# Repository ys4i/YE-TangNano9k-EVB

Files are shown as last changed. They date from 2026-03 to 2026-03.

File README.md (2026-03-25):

# YE-TangNano9k-EValuationBoard

コミックマーケット(C106)同人誌用TangNano9kの開発ボードです  
某月電子通商 Bタイプ基板(95×72mm)と寸法に互換性があります  
`販売コード[110243] B基板用アクリルパネル(アクリル板) 2mm厚(透明)`  
などでパネルを作れます

Tang Nano 9Kを用いた評価用ボードです。KiCad 9.0.3で設計されており、コミックマーケット(C106)頒布向けに作成されました。

## 特長
- 基板サイズ: 95 mm × 72 mm。某月電子通商 Bタイプ基板と同寸で、市販のB基板用アクリルパネルが使用可能。
- Seeed Studio製Tang Nano 9Kモジュールを搭載 (U1)。
- 24ピン×2列の拡張用ソケットコネクタを左右に配置 (J1, J2)。
- 4桁7セグメントLED表示器 OSL40391-IRA を搭載し、簡単な数値表示が可能。
- ブザー UGCM1205XP と、駆動用NPNトランジスタ 2SC1815 (Q1) を装備。
- 入力インターフェースとして SPDTスイッチ (SW1) とタクトスイッチ2個 (SW2, SW3) を搭載。

## プロジェクト構成
- `YE-tangnano9k-EVB.kicad_pro` : プロジェクト設定ファイル
- `YE-tangnano9k-EVB.kicad_sch` : 回路図
- `YE-tangnano9k-EVB.kicad_pcb` : 基板レイアウト
- `docs/YE-tangnano9k-EVB.pdf` : 回路図・基板図の閲覧用PDF
- `sym-lib-table` : シンボルライブラリ設定

## 使い方
KiCad 9.0以降で `.kicad_pro` ファイルを開き、回路図や基板データを編集してください。ファイル形式の詳細は [KiCad File Formats Documentation](https://dev-docs.kicad.org/en/file-formats/index.html) を参照してください。

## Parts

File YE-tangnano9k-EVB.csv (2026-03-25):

Reference | Qty | Value | Footprint | Datasheet
U2 | 1 | OSL40391-IRA | yasushi:OSL40391-Ixx | https://akizukidenshi.com/catalog/g/g109970/
U1 | 1 | Tang Nano 9K | yasushi:tangnano9k
SW2,SW3 | 2 | SW_Push | Button_Switch_THT:SW_PUSH_6mm_H7.3mm
SW1 | 1 | SW_SPDT | yasushi:2MS1-T1-B4-VS2-Q-E-S
R9,R11 | 2 | 10k | Resistor_THT:R_Axial_DIN0207_L6.3mm_D2.5mm_P10.16mm_Horizontal
R1,R2,R3,R4,R5,R6,R7,R8,R10 | 9 | 680 | Resistor_THT:R_Axial_DIN0207_L6.3mm_D2.5mm_P10.16mm_Horizontal
Q1 | 1 | 2SC1815 | Package_TO_SOT_THT:TO-92_Inline_Wide | https://media.digikey.com/pdf/Data%20Sheets/Toshiba%20PDFs/2SC1815.pdf
J1,J2 | 2 | Conn_01x24_Socket | Connector_PinSocket_2.54mm:PinSocket_1x24_P2.54mm_Vertical
BZ1 | 1 | UGCM1205XP | Buzzer_Beeper:Buzzer_12x9.5RM7.6

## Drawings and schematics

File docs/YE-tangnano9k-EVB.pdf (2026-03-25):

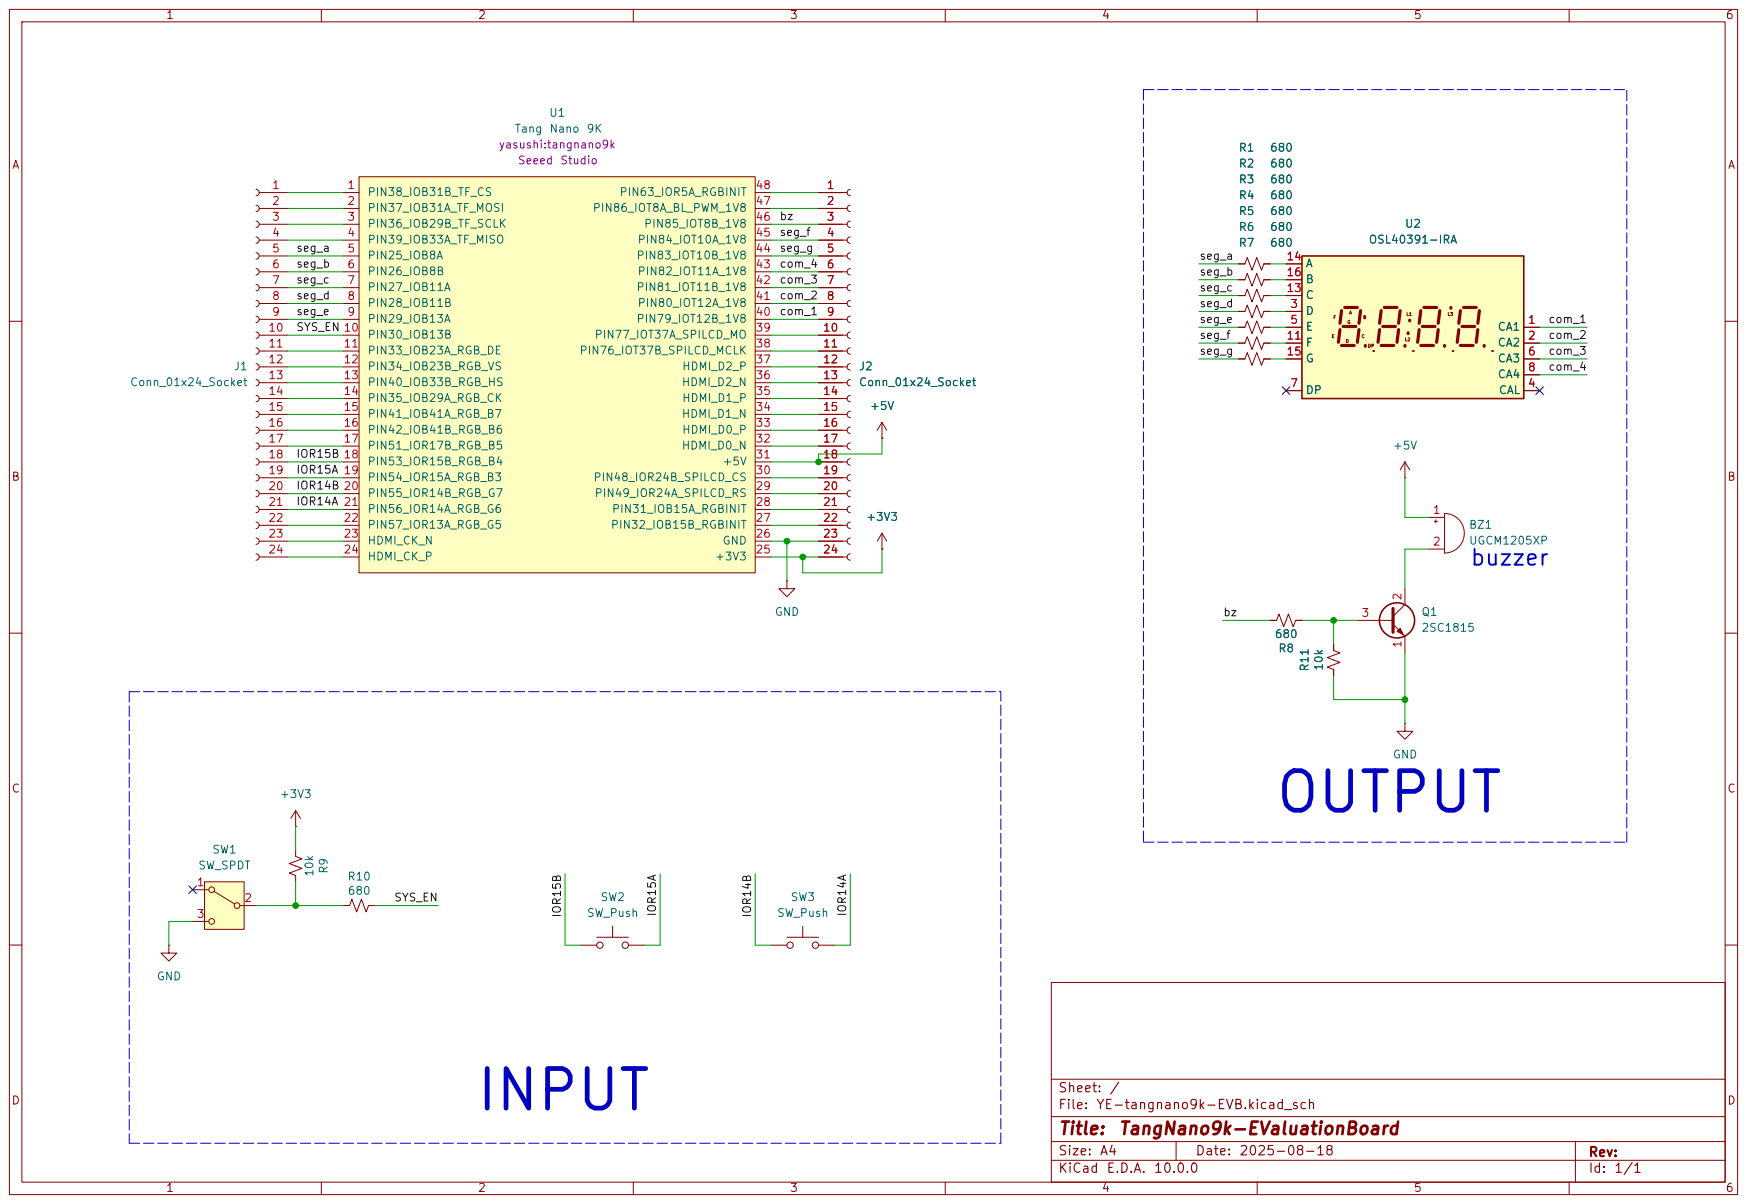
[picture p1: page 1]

Size: A4 | Rev:

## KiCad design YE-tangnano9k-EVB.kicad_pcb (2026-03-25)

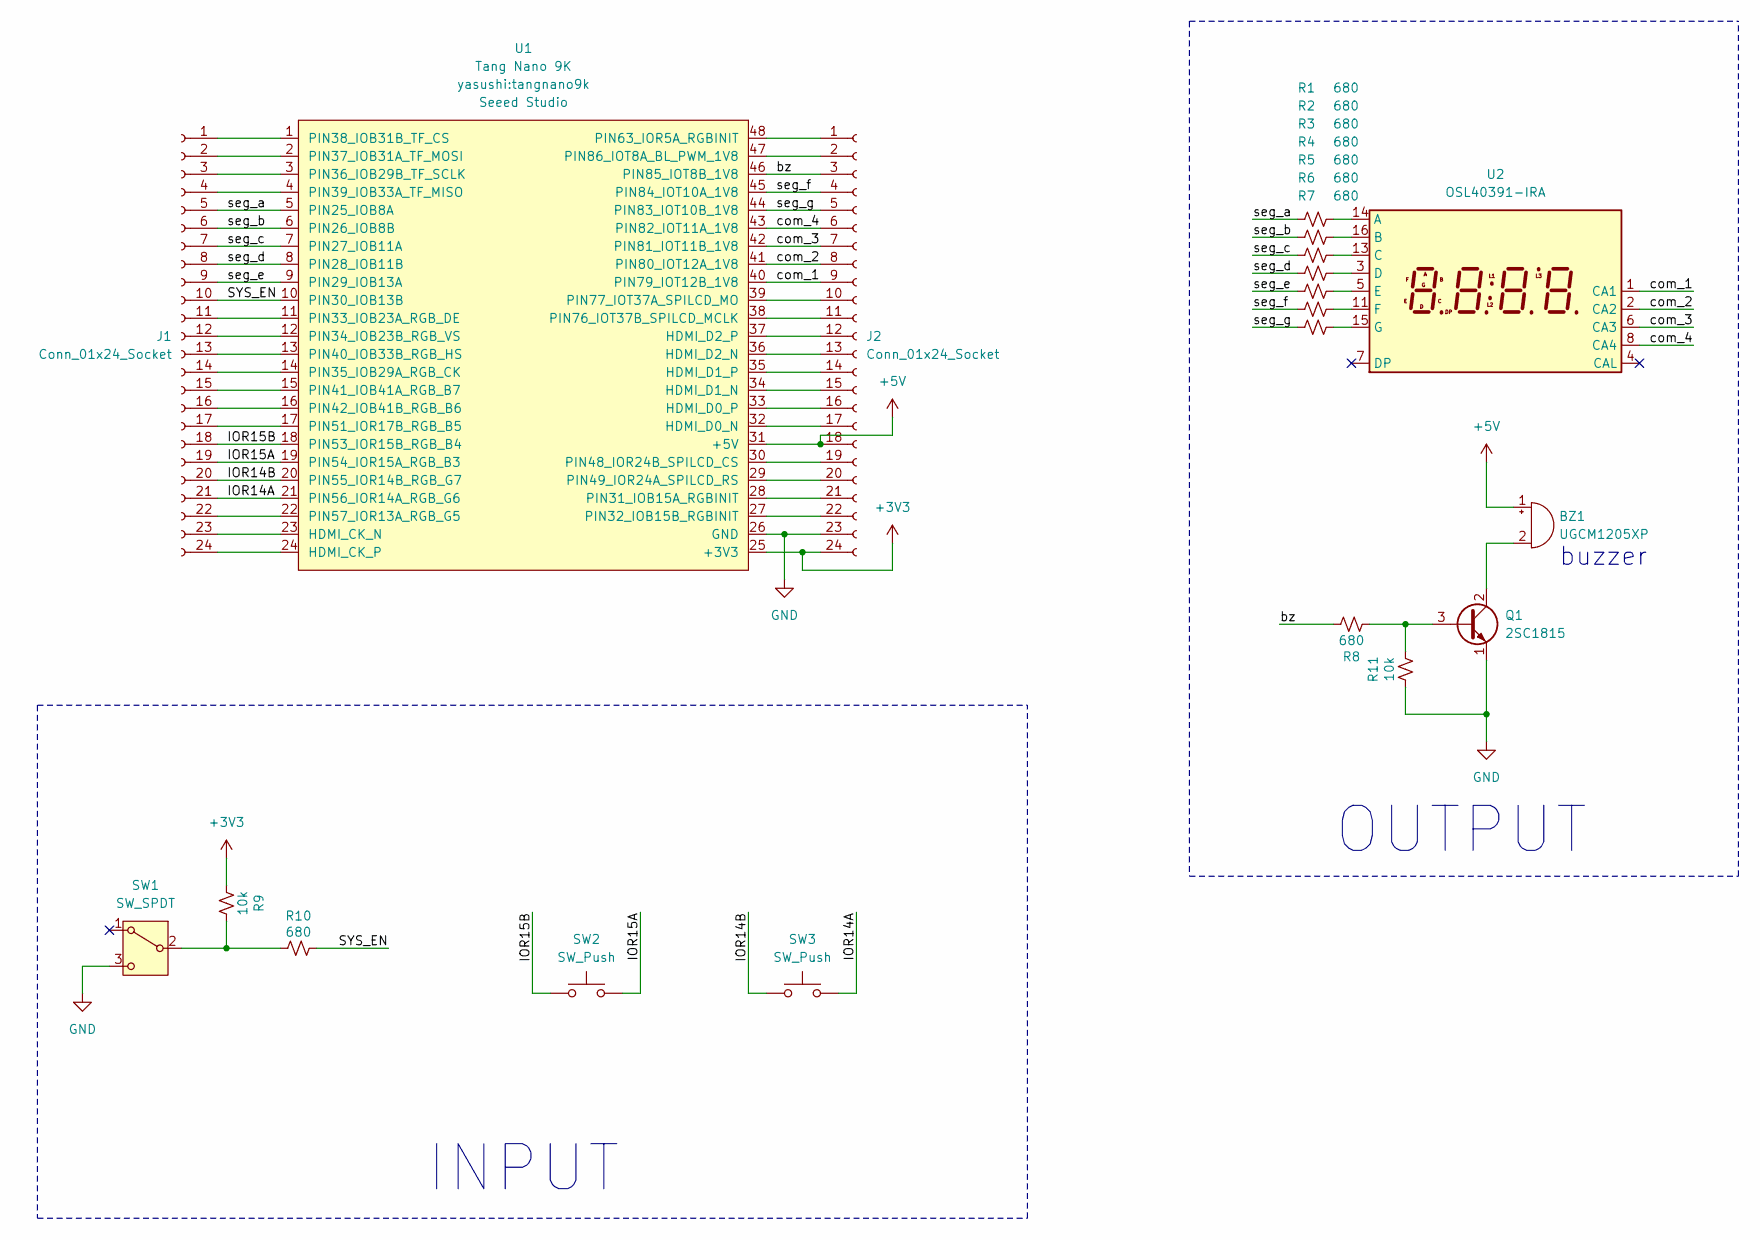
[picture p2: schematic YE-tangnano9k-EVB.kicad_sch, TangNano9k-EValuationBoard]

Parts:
BZ1: UGCM1205XP; Buzzer_12x9.5RM7.6
J1, J2: Conn_01x24_Socket; PinSocket_1x24_P2.54mm_Vertical
Q1: 2SC1815; TO-92_Inline_Wide
R1, R2, R3, R4, R5, R6, R7, R8, R10: 680; R_Axial_DIN0207_L6.3mm_D2.5mm_P10.16mm_Horizontal
R9, R11: 10k; R_Axial_DIN0207_L6.3mm_D2.5mm_P10.16mm_Horizontal
SW1: SW_SPDT; 2MS1-T1-B4-VS2-Q-E-S
SW2, SW3: SW_Push; SW_PUSH_6mm_H7.3mm
U1: Tang Nano 9K; tangnano9k
U2: OSL40391-IRA; OSL40391-Ixx

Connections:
+3V3: J2.24, R9.1, U1.25 (+3V3)
+5V: BZ1.1 (+), J2.18, U1.31 (+5V)
/IOR14A: J1.21, SW3.2, U1.21 (PIN56_IOR14A_RGB_G6)
/IOR14B: J1.20, SW3.1, U1.20 (PIN55_IOR14B_RGB_G7)
/IOR15A: J1.19, SW2.2, U1.19 (PIN54_IOR15A_RGB_B3)
/IOR15B: J1.18, SW2.1, U1.18 (PIN53_IOR15B_RGB_B4)
/SYS_EN: J1.10, R10.2, U1.10 (PIN30_IOB13B)
/bz: J2.3, R8.2, U1.46 (PIN85_IOT8B_1V8)
/com_1: J2.9, U1.40 (PIN79_IOT12B_1V8), U2.1 (CA1)
/com_2: J2.8, U1.41 (PIN80_IOT12A_1V8), U2.2 (CA2)
/com_3: J2.7, U1.42 (PIN81_IOT11B_1V8), U2.6 (CA3)
/com_4: J2.6, U1.43 (PIN82_IOT11A_1V8), U2.8 (CA4)
/seg_a: J1.5, R1.1, U1.5 (PIN25_IOB8A)
/seg_b: J1.6, R2.1, U1.6 (PIN26_IOB8B)
/seg_c: J1.7, R3.1, U1.7 (PIN27_IOB11A)
/seg_d: J1.8, R4.1, U1.8 (PIN28_IOB11B)
/seg_e: J1.9, R5.1, U1.9 (PIN29_IOB13A)
/seg_f: J2.4, R6.1, U1.45 (PIN84_IOT10A_1V8)
/seg_g: J2.5, R7.1, U1.44 (PIN83_IOT10B_1V8)
GND: J2.23, Q1.1 (E), R11.1, SW1.3 (C), U1.26 (GND)
unnamed: BZ1.2 (-), Q1.2 (C)
unnamed: J1.1, U1.1 (PIN38_IOB31B_TF_CS)
unnamed: J1.2, U1.2 (PIN37_IOB31A_TF_MOSI)
unnamed: J1.3, U1.3 (PIN36_IOB29B_TF_SCLK)
unnamed: J1.4, U1.4 (PIN39_IOB33A_TF_MISO)
unnamed: J1.11, U1.11 (PIN33_IOB23A_RGB_DE)
unnamed: J1.12, U1.12 (PIN34_IOB23B_RGB_VS)
unnamed: J1.13, U1.13 (PIN40_IOB33B_RGB_HS)
unnamed: J1.14, U1.14 (PIN35_IOB29A_RGB_CK)
unnamed: J1.15, U1.15 (PIN41_IOB41A_RGB_B7)
unnamed: J1.16, U1.16 (PIN42_IOB41B_RGB_B6)
unnamed: J1.17, U1.17 (PIN51_IOR17B_RGB_B5)
unnamed: J1.22, U1.22 (PIN57_IOR13A_RGB_G5)
unnamed: J1.23, U1.23 (HDMI_CK_N)
unnamed: J1.24, U1.24 (HDMI_CK_P)
unnamed: J2.1, U1.48 (PIN63_IOR5A_RGBINIT)
unnamed: J2.2, U1.47 (PIN86_IOT8A_BL_PWM_1V8)
unnamed: J2.10, U1.39 (PIN77_IOT37A_SPILCD_MO)
unnamed: J2.11, U1.38 (PIN76_IOT37B_SPILCD_MCLK)
unnamed: J2.12, U1.37 (HDMI_D2_P)
unnamed: J2.13, U1.36 (HDMI_D2_N)
unnamed: J2.14, U1.35 (HDMI_D1_P)
unnamed: J2.15, U1.34 (HDMI_D1_N)
unnamed: J2.16, U1.33 (HDMI_D0_P)
unnamed: J2.17, U1.32 (HDMI_D0_N)
unnamed: J2.19, U1.30 (PIN48_IOR24B_SPILCD_CS)
unnamed: J2.20, U1.29 (PIN49_IOR24A_SPILCD_RS)
unnamed: J2.21, U1.28 (PIN31_IOB15A_RGBINIT)
unnamed: J2.22, U1.27 (PIN32_IOB15B_RGBINIT)
unnamed: Q1.3 (B), R8.1, R11.2
unnamed: R9.2, R10.1, SW1.2 (B)
unnamed: R1.2, U2.14 (A)
unnamed: R2.2, U2.16 (B)
unnamed: R3.2, U2.13 (C)
unnamed: R4.2, U2.3 (D)
unnamed: R5.2, U2.5 (E)
unnamed: R6.2, U2.11 (F)
unnamed: R7.2, U2.15 (G)

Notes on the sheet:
OUTPUT
INPUT
buzzer

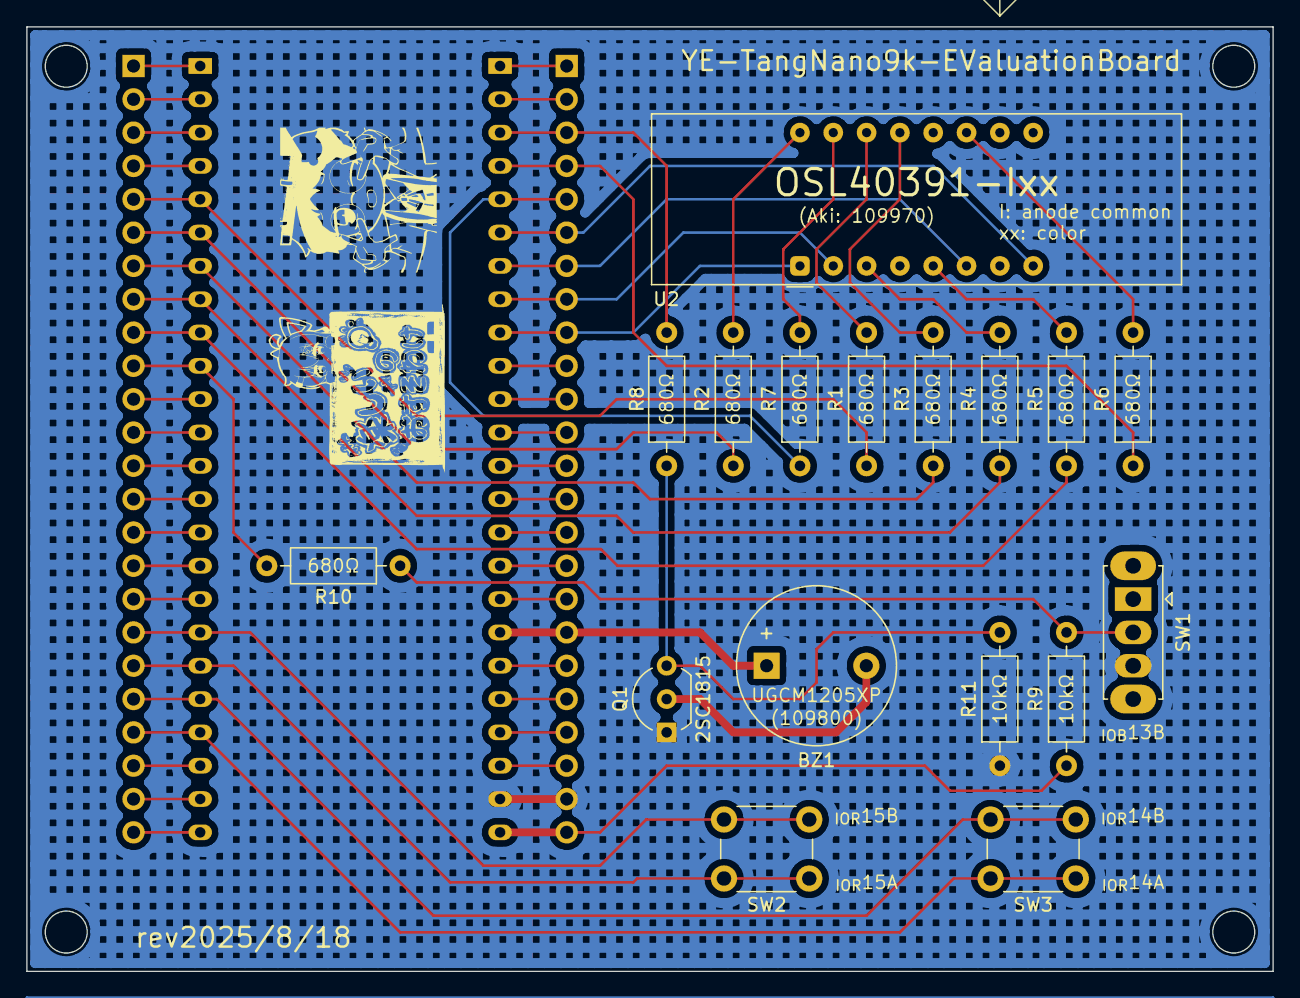
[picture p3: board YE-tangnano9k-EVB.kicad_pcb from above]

Board: 2 copper layers, 95.0 x 72.0 mm, 20 parts (0 on the bottom side), 58 nets.

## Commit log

2025-08-04 add yasushi_icon fix Front_silk
    [YE-tangnano9k-EVB.kicad_pcb]
2025-08-04 fix net_name
    [YE-tangnano9k-EVB.kicad_pcb, YE-tangnano9k-EVB.kicad_sch]
2025-08-05 change pushSW net change buzzer logic(ActiveHigh → ActiveLow)
    [YE-tangnano9k-EVB.kicad_pcb, YE-tangnano9k-EVB.kicad_sch]
2025-08-06 change Buzzer_logic (→ActiveHIGH) fix pcb
    [YE-tangnano9k-EVB.kicad_pcb, YE-tangnano9k-EVB.kicad_sch]
2025-08-06 fix silk font size
    [YE-tangnano9k-EVB.kicad_pcb, YE-tangnano9k-EVB.kicad_sch]
2025-08-06 add silk art
    [YE-tangnano9k-EVB.kicad_pcb]
2025-08-06 塗りつぶしをmeshに変更
    [YE-tangnano9k-EVB.kicad_pcb]
2025-08-06 meshのみを下に置いとく
    [YE-tangnano9k-EVB.kicad_pcb]
2025-08-06 fix BottomMask Layer
    [YE-tangnano9k-EVB.kicad_pcb]
2025-08-08 fix date
    [YE-tangnano9k-EVB.kicad_sch]
2025-08-08 Insert original project description
2025-08-17 fix silk(buzzer)
    [YE-tangnano9k-EVB.kicad_pcb]
2025-08-17 fix revision date
    [YE-tangnano9k-EVB.kicad_pcb, YE-tangnano9k-EVB.kicad_sch]
2026-03-25 add schematic gitignore
    [YE-tangnano9k-EVB.csv, YE-tangnano9k-EVB.kicad_pcb, YE-tangnano9k-EVB.kicad_sch]
2026-03-25 Add .gitignore for local KiCad artifacts and backups
2026-03-25 README: docs内PDFへの案内を追加
